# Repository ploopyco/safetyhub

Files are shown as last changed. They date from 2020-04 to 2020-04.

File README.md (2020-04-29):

# The Ploopy Safetyhub

If you're a certain kind of tinkerer, you probably have a whole bunch of computers with busted USB ports. Maybe you dropped a screwdriver on a dev board one time, or accidentally charged your EV prototype through the debugging interface. Either way, you oopsied and now your shiny Thinkpad (or Macbook, we don't judge) has a dead USB port.

A "simple" way to avoid this problem is to use a "powered" USB hub, which protects the upstream port from downstream mischief. The fact that we looked for a reliable one and couldn't find it is the reason this project exists. In short:

## The Ploopy Safetyhub was explicitly designed to protect your computer from the antics of your bus-powered devices. No more murdering the USB ports on your shiny computer!

Specifically:

- The 5V line from the upstream data port is not connected to any downstream 5V lines, so a downstream short can't damage your computer.
- The data lines have good ESD protection on both the upstream and downstream sides, serving as a first (and second) line of defense against ESD strikes.
- Downstream 5V lines have FET-based (fast, recoverable) over-current protection for downstream shorts. All downstream 5V power comes from a separate USB-C port (which would typically have a robust wall-wart plugged into it).

Spec-wise:

- 3 downstream USB 2.0 ports, including one port rated for 1.5A charging.
- Microchip USB2513B hub controller.
- Separate upstream USB-C connectors for data (USB 2.0) and power (up to 3A).
- LED indicators to indicate whether a port is active/faulted.
- No direct connections between upstream and downstream power/data lines.
- Heavy-duty ESD protection (IEC 61000-4-2 class 4).

The way it works is simple: there are no direct power/data connections between your computer and downstream devices. Power comes from a sturdy wall-wart, and beefy ESD protection makes sure nothing zappy makes it to your computer. As long as your device is bus-powered (i.e. doesn't have a power supply of its' own), the Safetyhub should protect your computer.

## Schematics

Electrical design files are in Altium-specific formats, but if you just want to look, there's a PDF version here: https://github.com/ploopyco/safetyhub/blob/master/Electrical/HubSchematics.pdf

## Obligatory Warnings

The Safetyhub is not electrically isolated, and won't protect from high voltages, ground loops and other dangerous situations. If your downstream device has its' own power supply/has high voltages present/presents other electrical hazards, you'll need a real isolation barrier. If you're not sure if this paragraph describes your situation, please consult with someone who can help you avoid electrocution/accidents that give you superpowers.

## Under what license is this released?

The hub is released under OHL CERN v1.2. Check the respective directories for full license text.

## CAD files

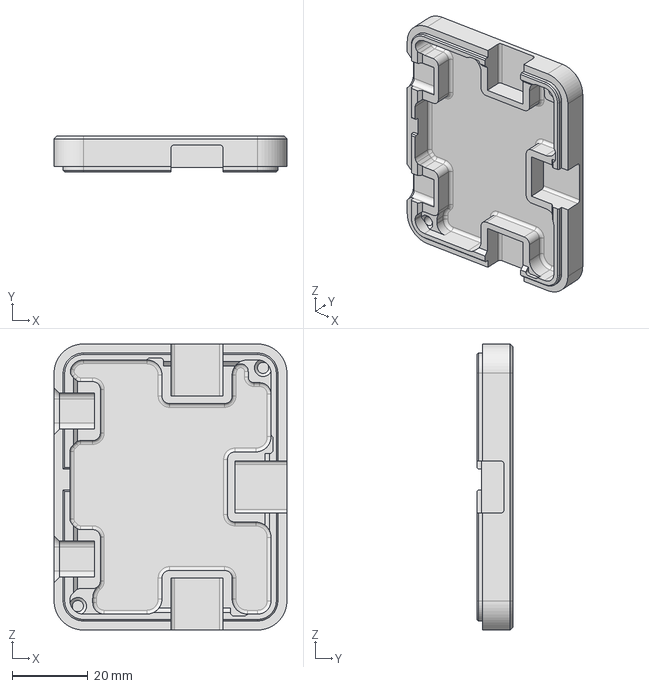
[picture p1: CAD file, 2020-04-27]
Mechanical/STEPs/HUB-001.stp
61.4 x 9.58 x 75.4 mm

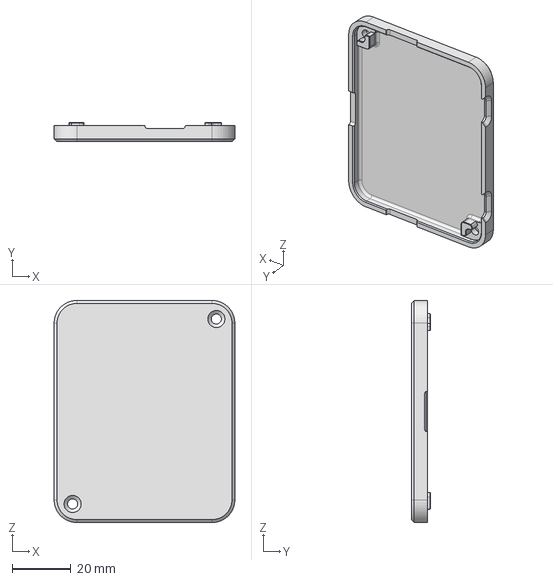
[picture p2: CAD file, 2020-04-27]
Mechanical/STEPs/HUB-002.stp
61.4 x 6.60 x 75.4 mm

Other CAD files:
Mechanical/STLs/HUB-001.stl
Mechanical/STLs/HUB-002.stl

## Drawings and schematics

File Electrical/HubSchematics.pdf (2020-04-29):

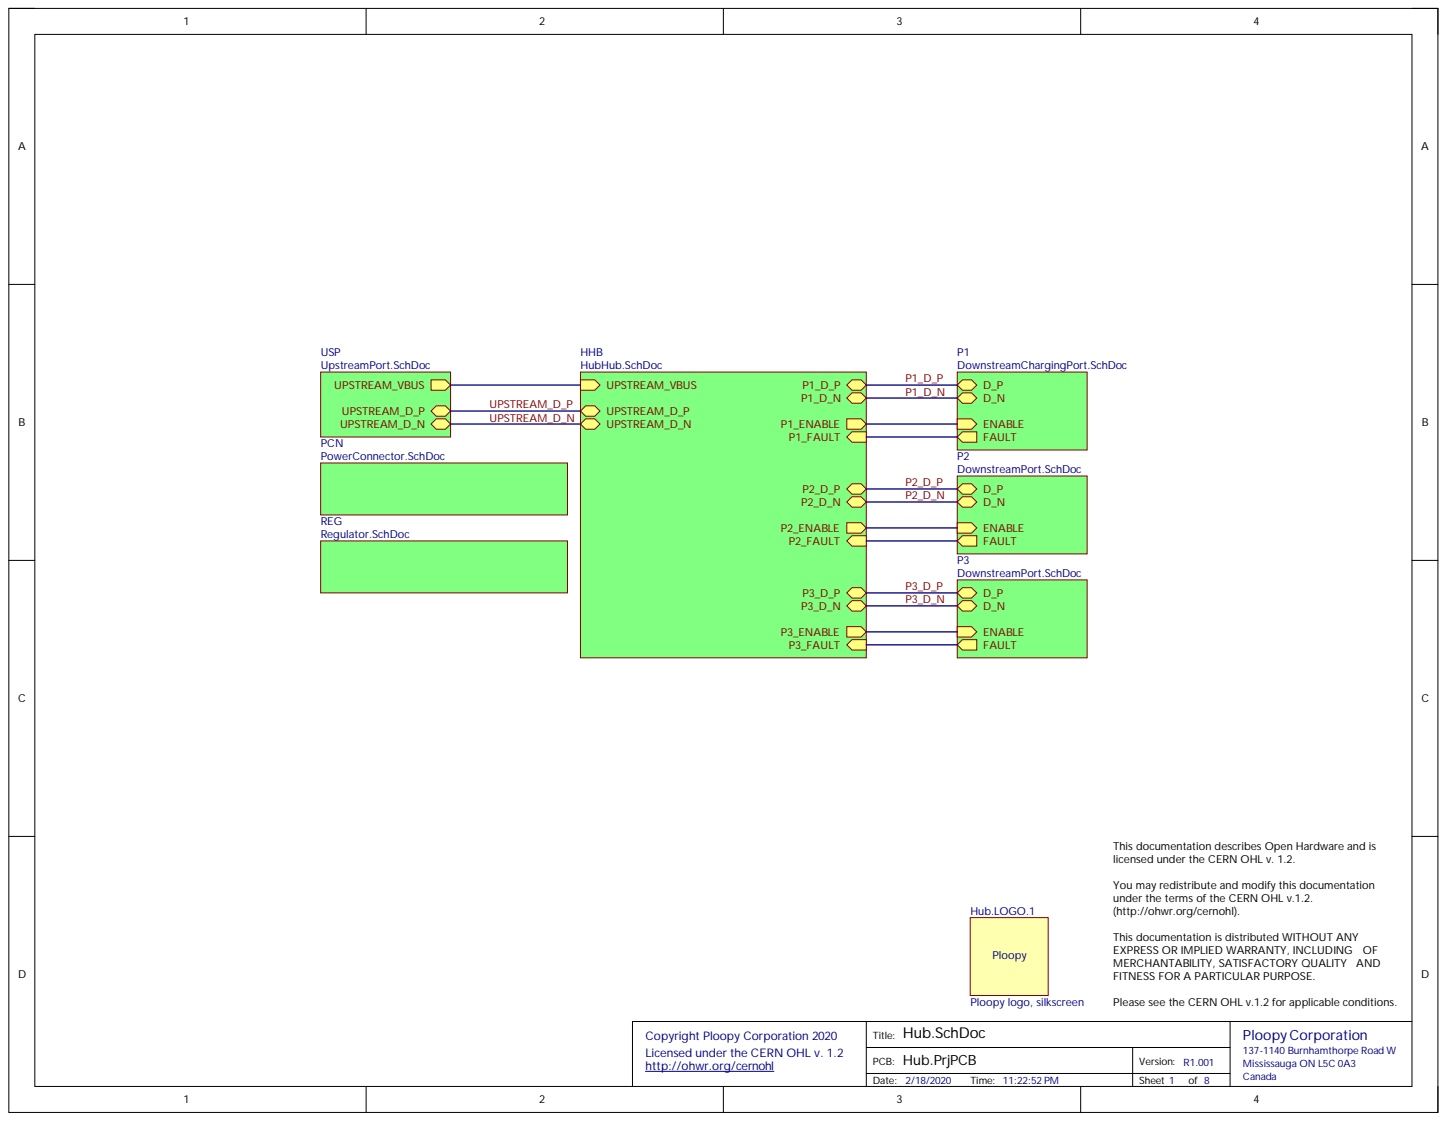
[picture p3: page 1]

This documentation describes Open Hardware and is
licensed under the CERN OHL v. 1.2.

You may redistribute and modify this documentation
under the terms of the CERN OHL v.1.2.
(http://ohwr.org/cernohl).

This documentation is distributed WITHOUT ANY
EXPRESS OR IMPLIED WARRANTY, INCLUDING OF
MERCHANTABILITY, SATISFACTORY QUALITY AND
FITNESS FOR A PARTICULAR PURPOSE.

Please see the CERN OHL v.1.2 for applicable conditions.

Copyright Ploopy Corporation 2020
Licensed under the CERN OHL v. 1.2
http://ohwr.org/cernohl

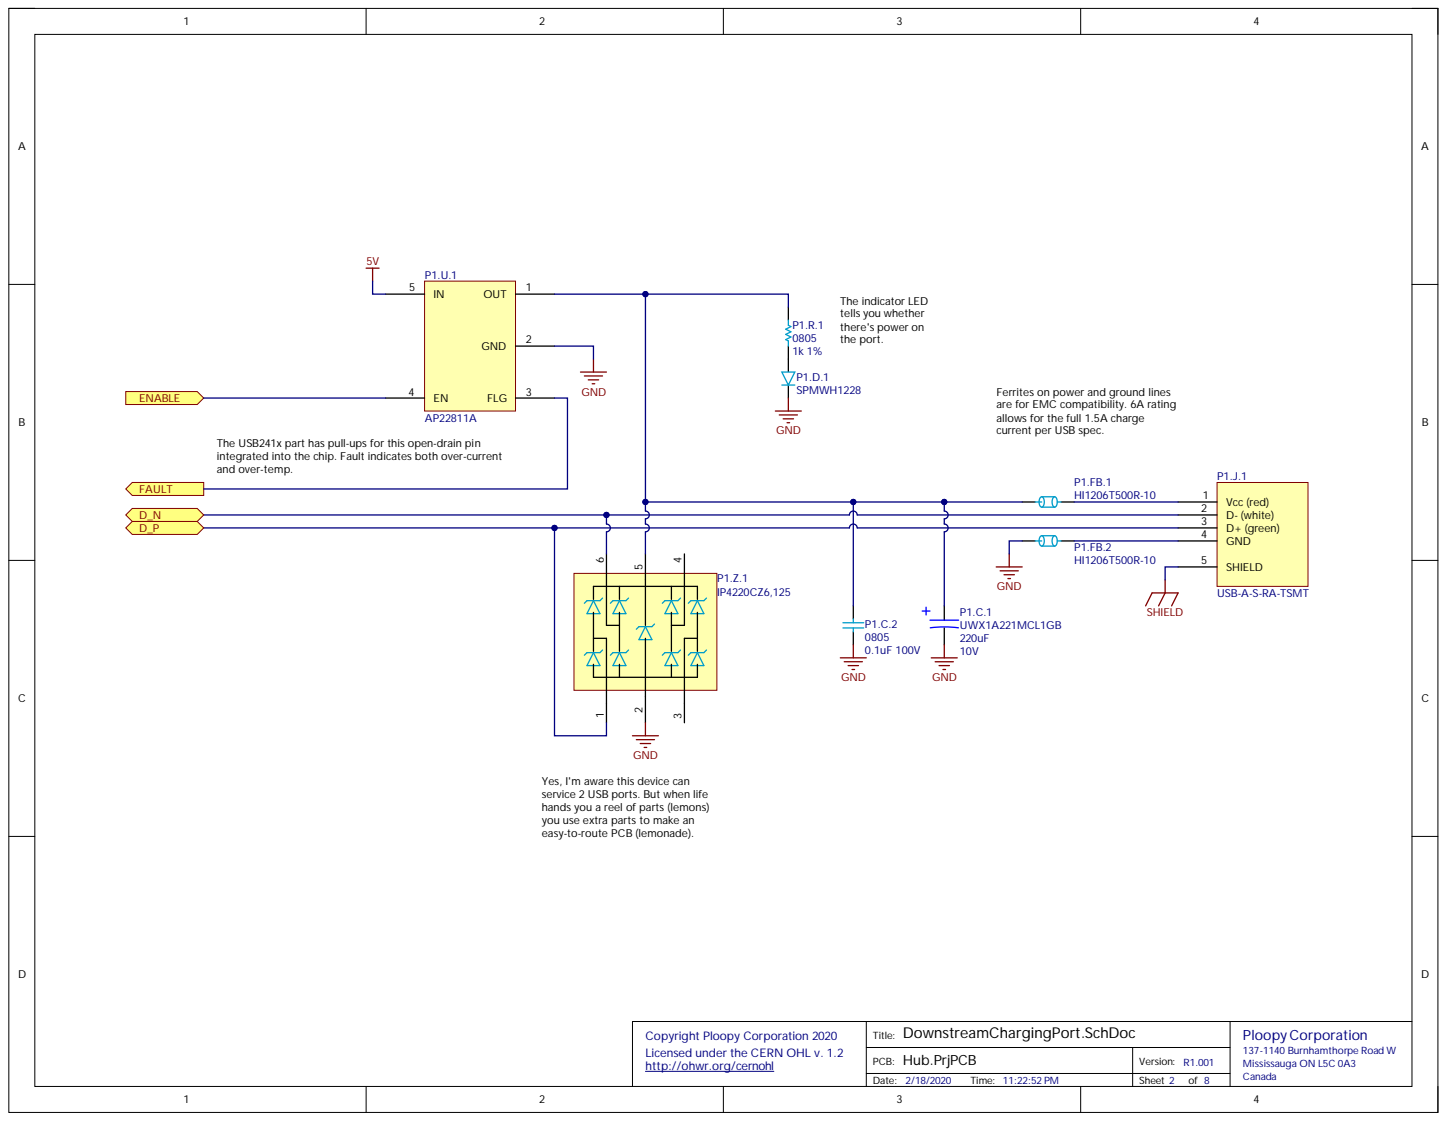
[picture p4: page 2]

Ferrites on power and ground lines
are for EM
allows for the full 1.5A charge
current per USB s

The USB
integrated into the chip. Fault indicates both over-current
and over-tem

41x part has pull-up

Yes, I'm aware this device can service 2 USB ports. But when life

s you a reel of parts (lemons)
hand
you use extra parts to make an
easy-to-route PC

Cop
Licensed under the CE
http

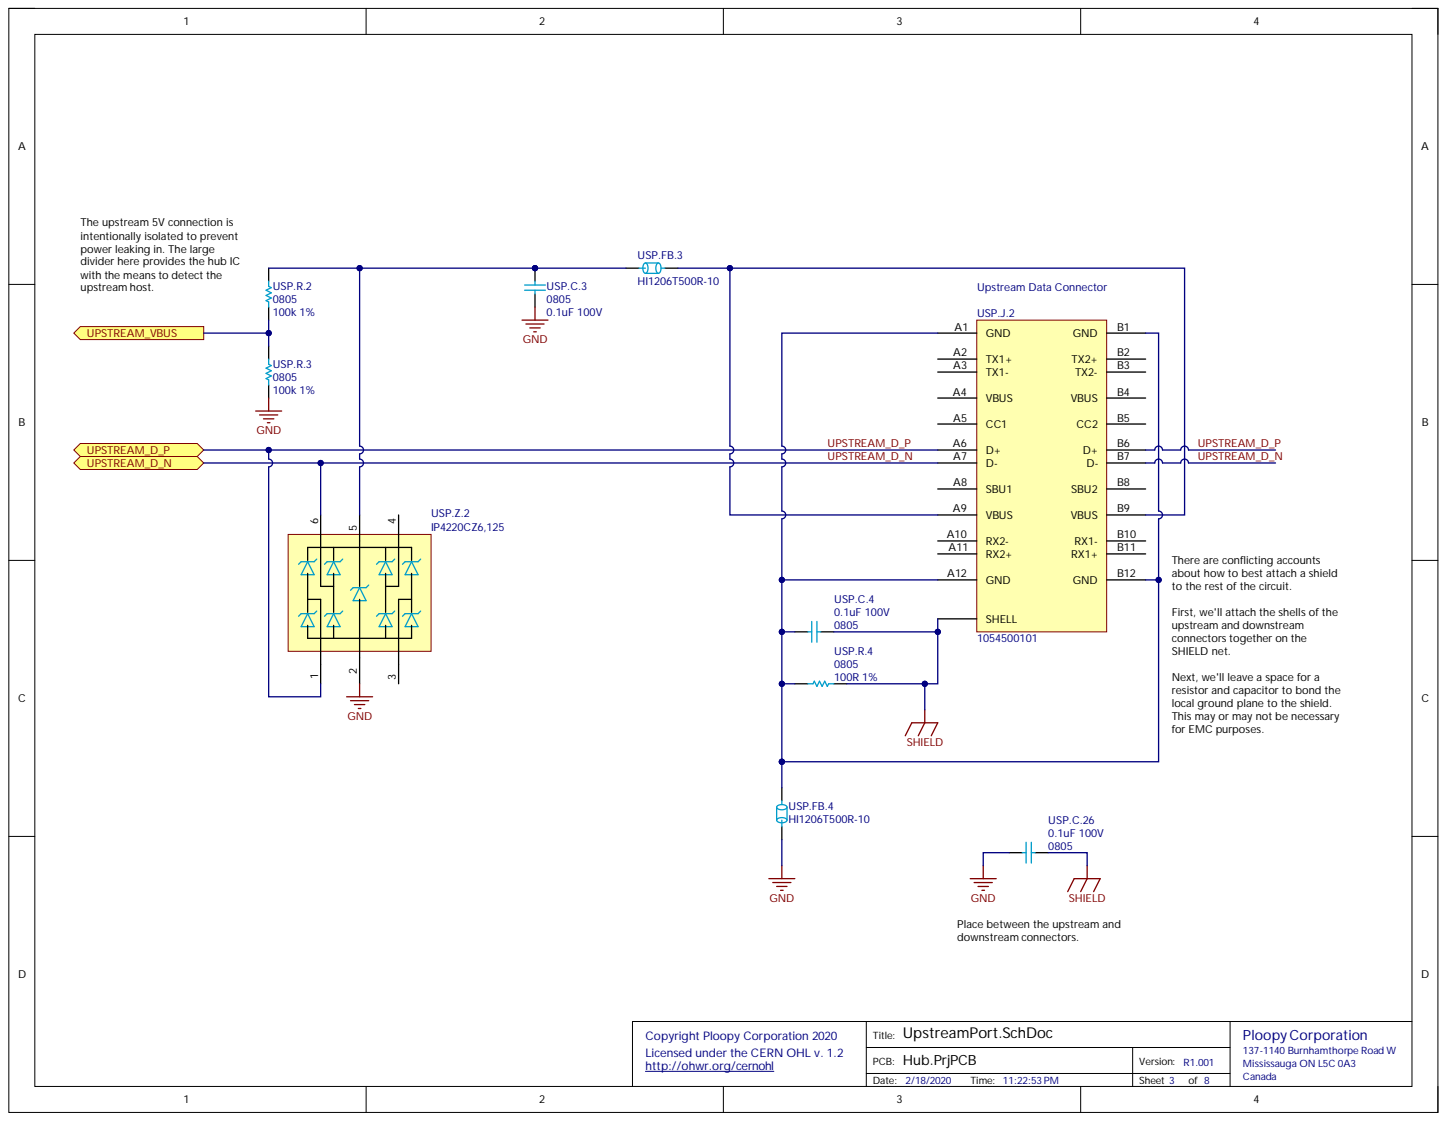
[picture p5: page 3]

The upstream 5V connection is
intentionally isolated to prevent
power leaking in. The large
divider here provides the hub IC
with the means to detect the
upstream host.

There are conflicting accounts
about how to best attach a shield
to the rest of the circuit.

First, we'll attach the shells of the
upstream and downstream
connectors together on the
SHIELD net.

Next, we'll leave a space for a
resistor and capacitor to bond the
local ground plane to the shield.
This may or may not be necessary
for EMC purposes.

Place between the upstream and
downstream connectors.

Copyright Ploopy Corporation 2020
Licensed under the CERN OHL v. 1.2
http://ohwr.org/cernohl

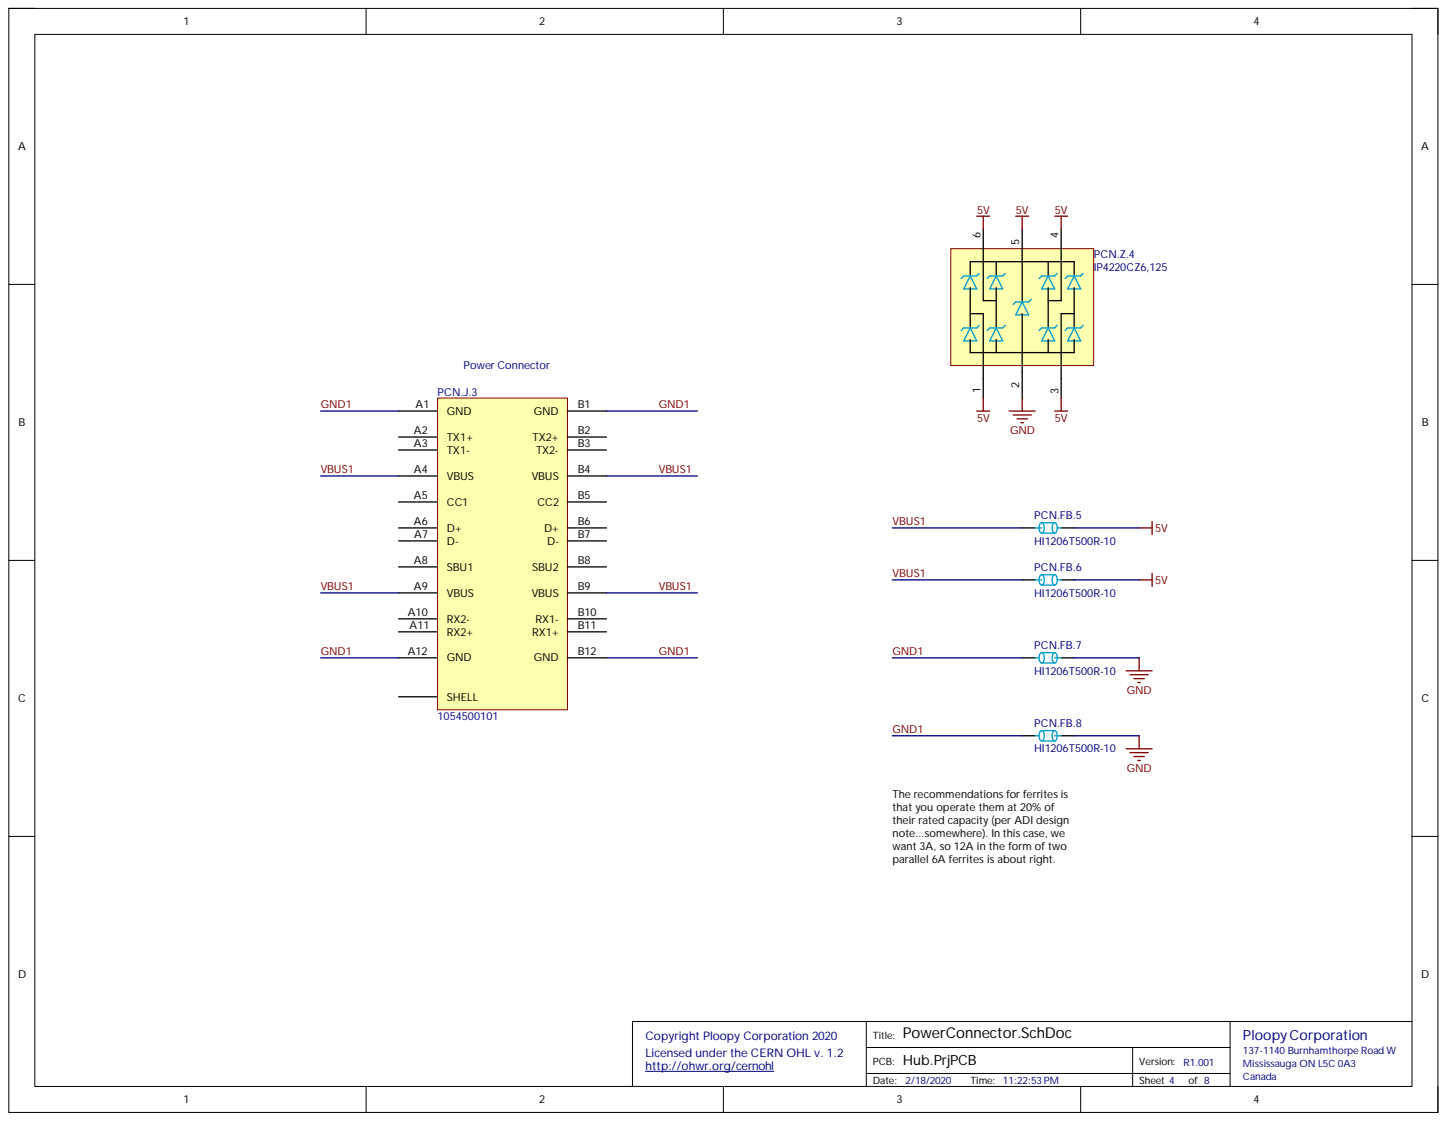
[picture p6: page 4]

The recom
that you operate them at 20% of
their rated capacity (per A
note...somewhere).
want 3A, so 12A in the form of two parallel 6A ferrites is about right.

mendations for ferrites is

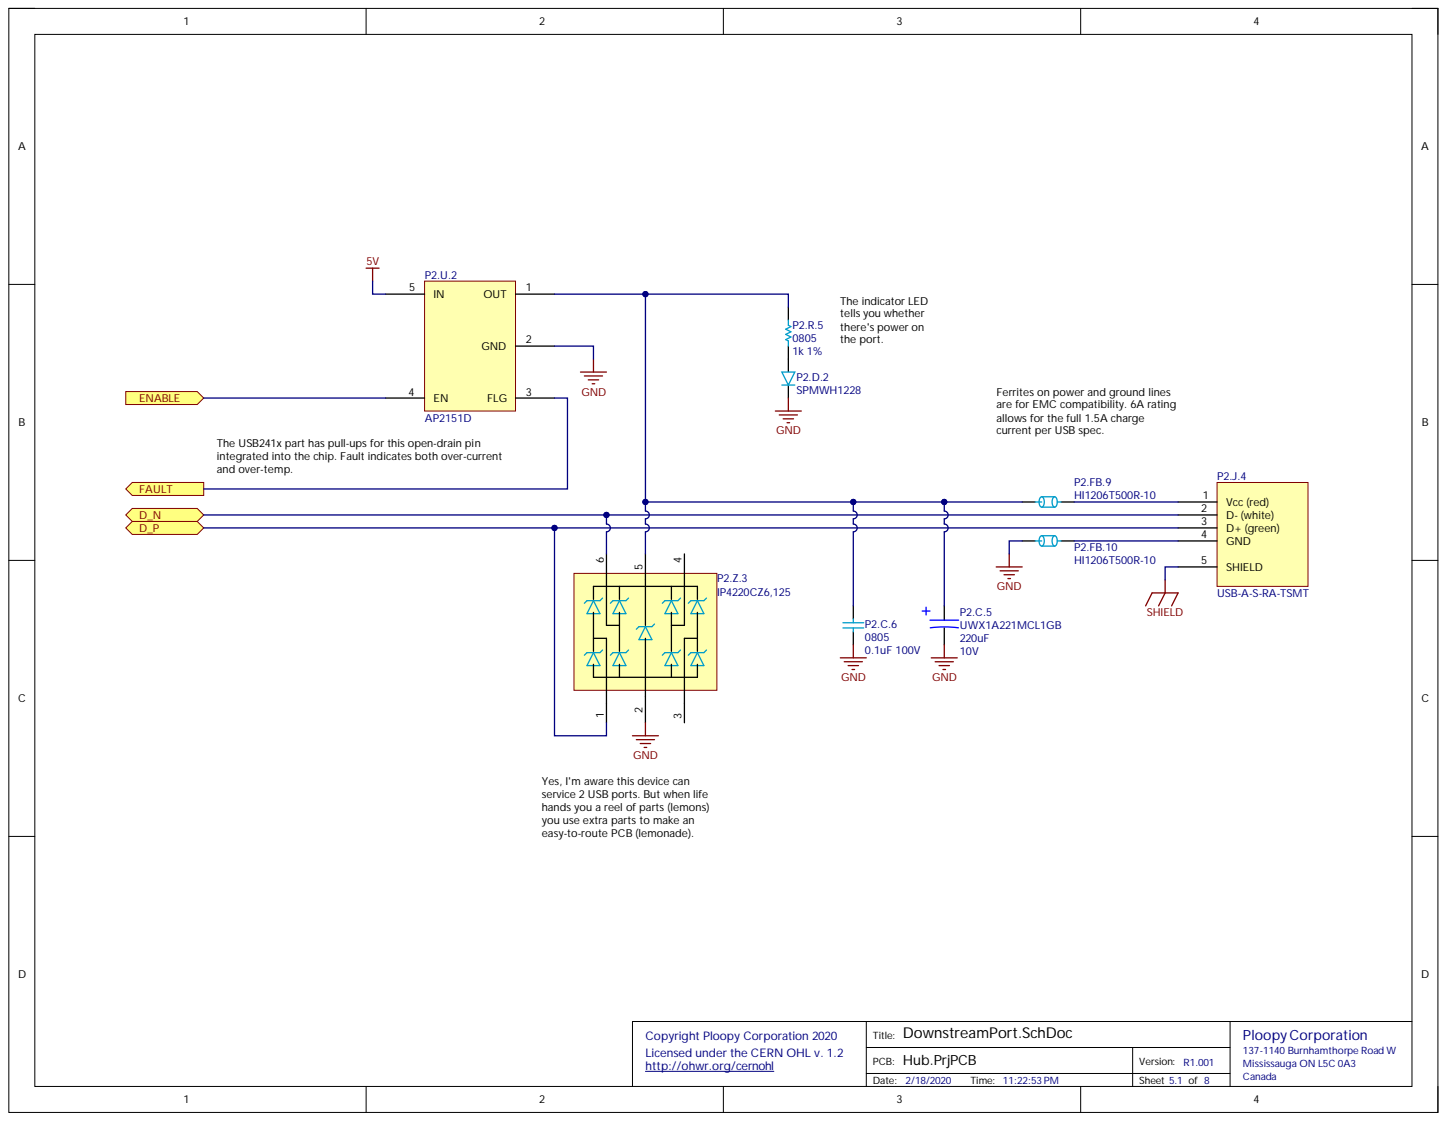
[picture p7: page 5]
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

The USB
integrated into the chip. Fault indicates both over-current
and over-tem

41x part has pull-up

Yes, I'm aware this device can service 2 USB ports. But when life

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

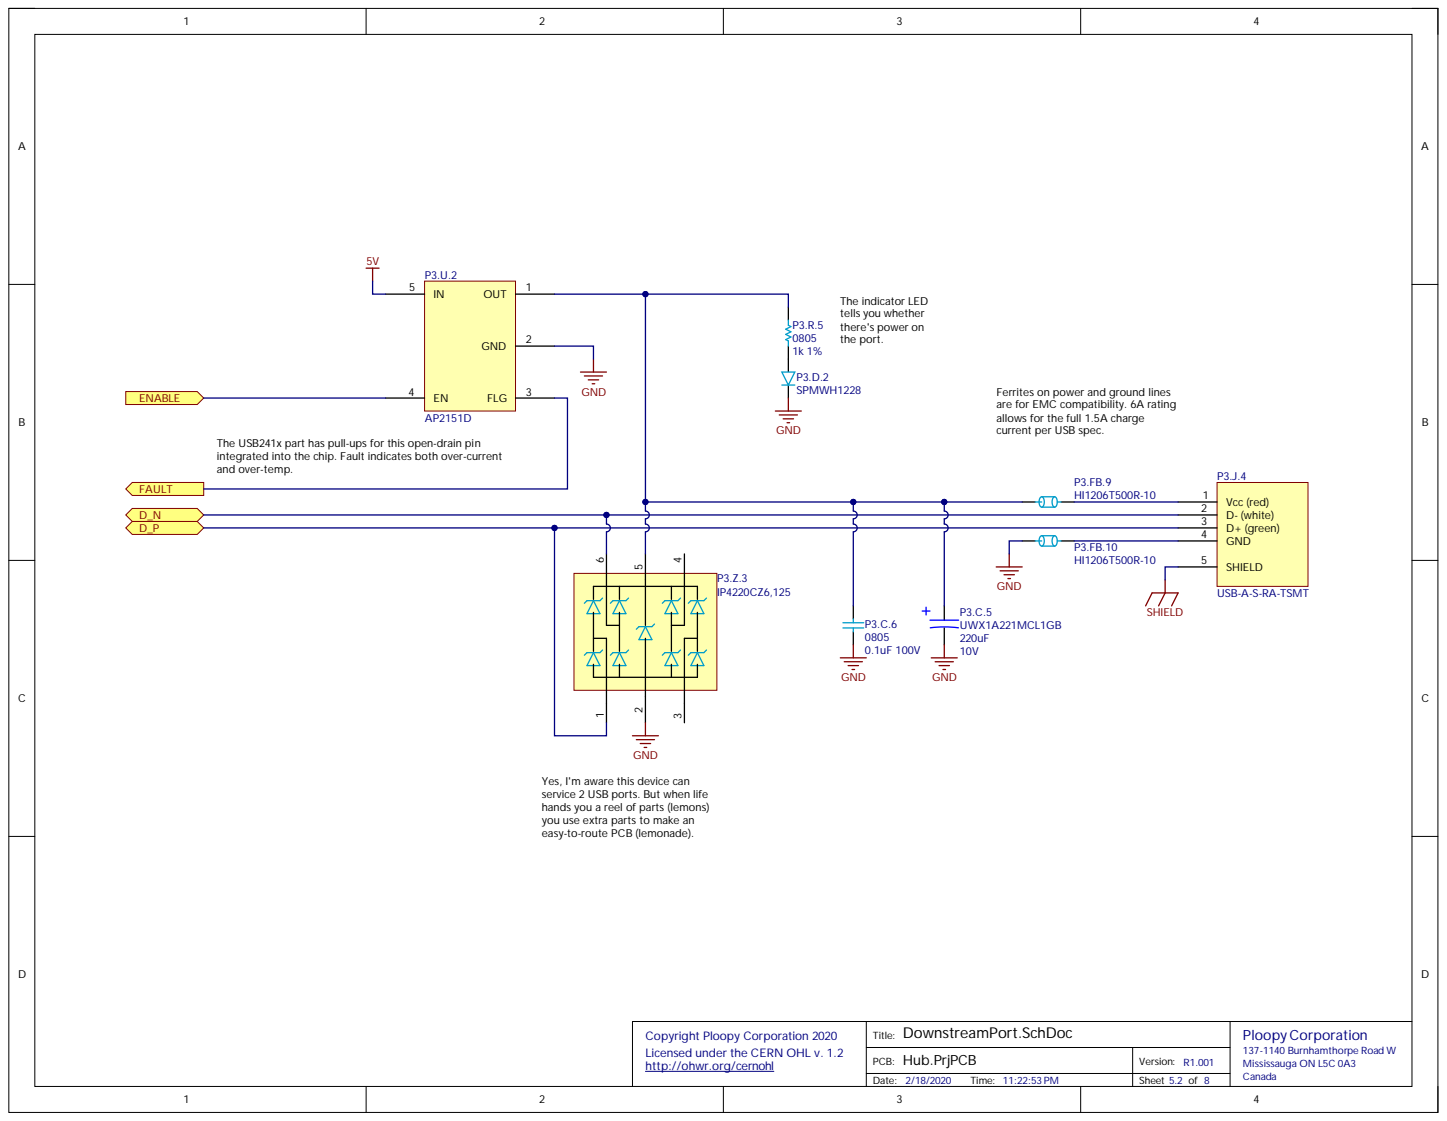
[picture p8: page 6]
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

The USB
integrated into the chip. Fault indicates both over-current
and over-tem

41x part has pull-up

Yes, I'm aware this device can service 2 USB ports. But when life

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

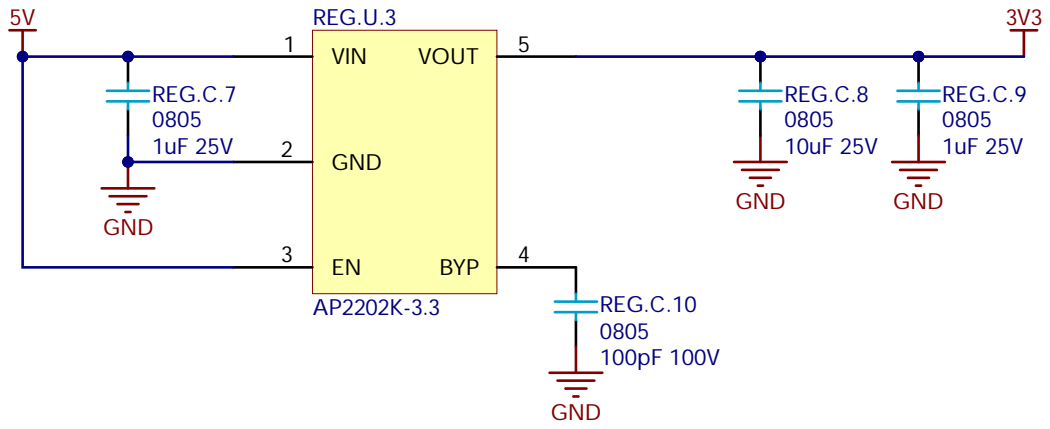
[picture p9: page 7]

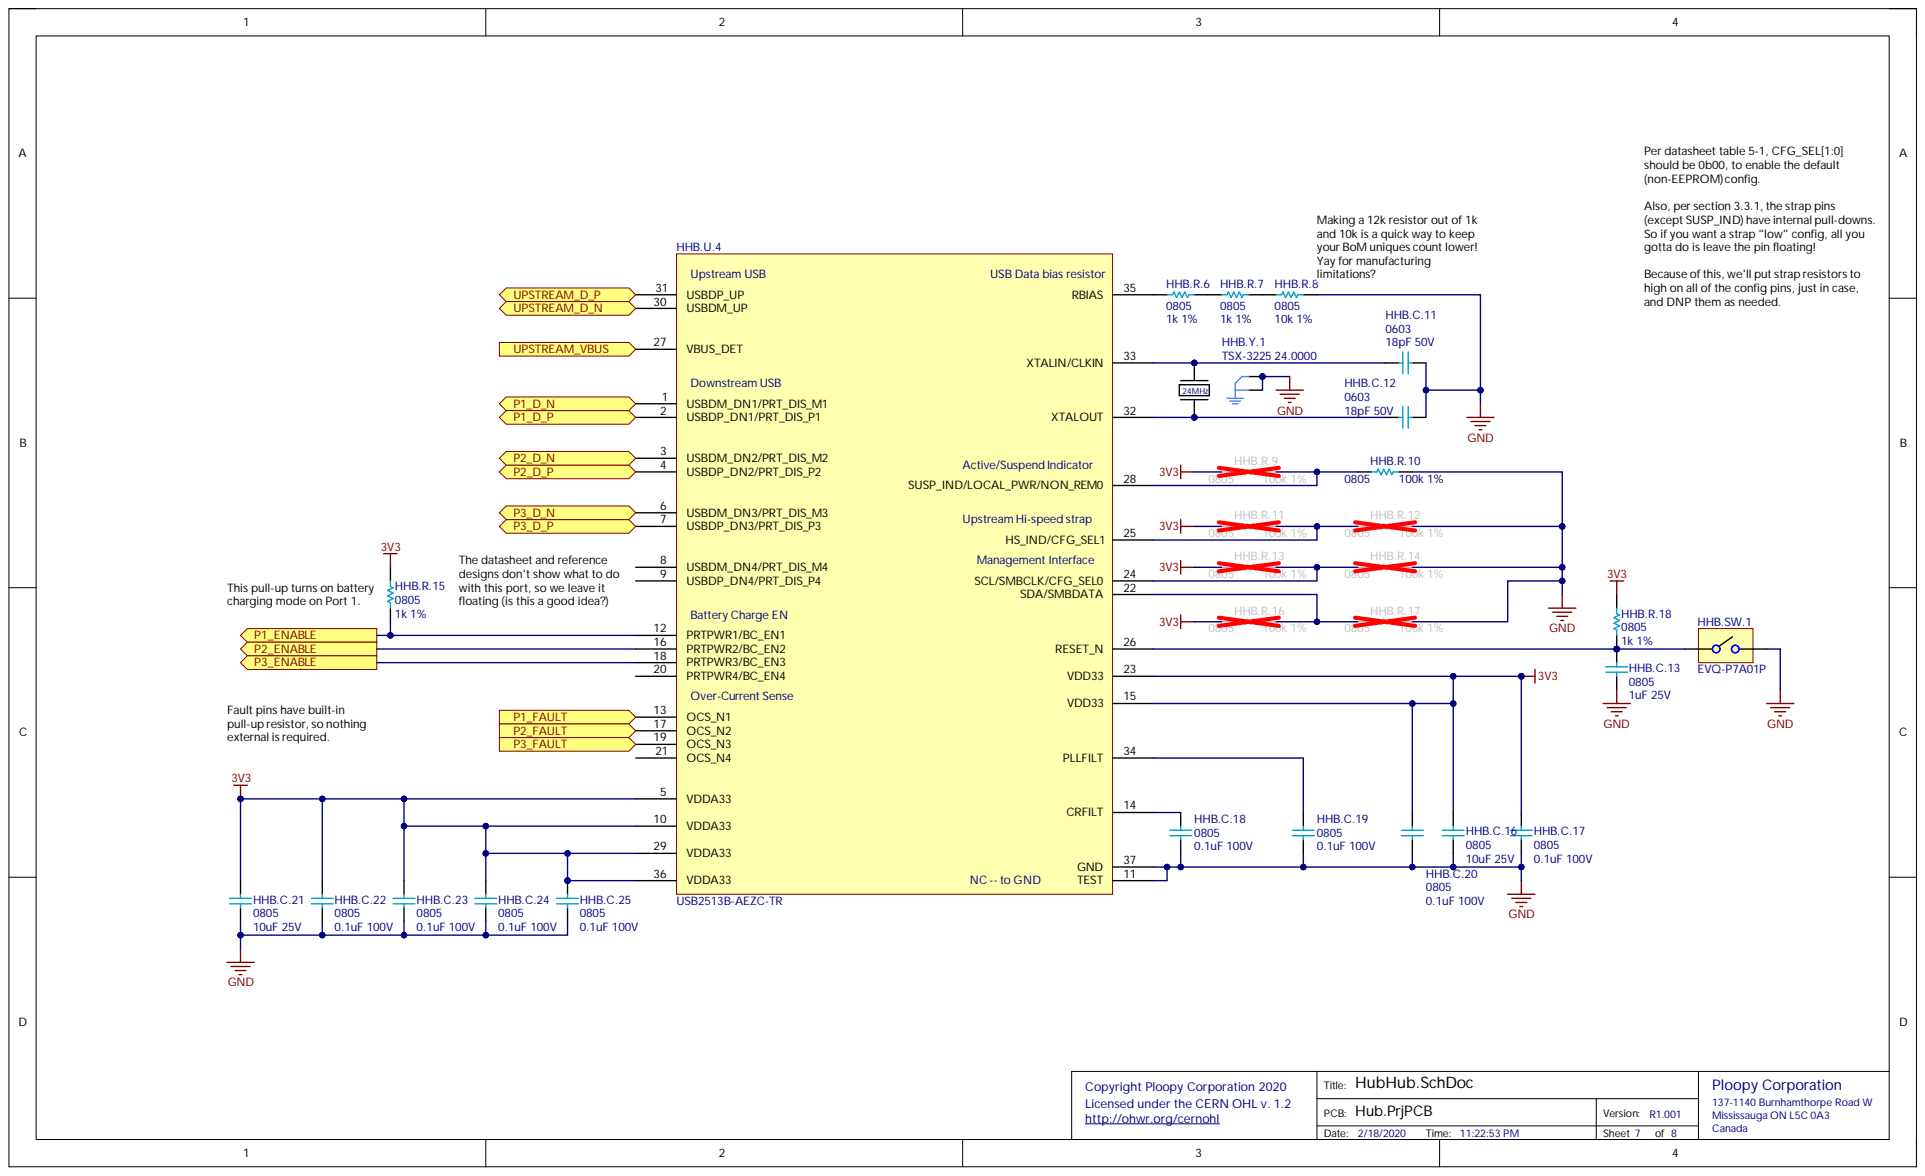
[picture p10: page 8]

USBDM_U
Downstream USB Battery Charge EN Over-Current Sense
USBDM_DN1/PR

ing mode on Port 1.

C opy righ t Plo opy C o rpo ratio n 2 0 2 0 Lice n sed u nde r t h e CERN O HL v. 1.2 h t tp://o hwr.o rg/ce r n o h l | T i t le: HubHub .SchD o c | Ploop y Corporation 137-1140 Burnha m tho rpe Ro ad W M i ss i ssauga ON L5C 0A 3 C anada

Hub.PrjPC B P C B : | Vers i o n : R1.001

D a te: 2/18/2020 T i me: 11:22:53 P M | Sheet 7 o f 8

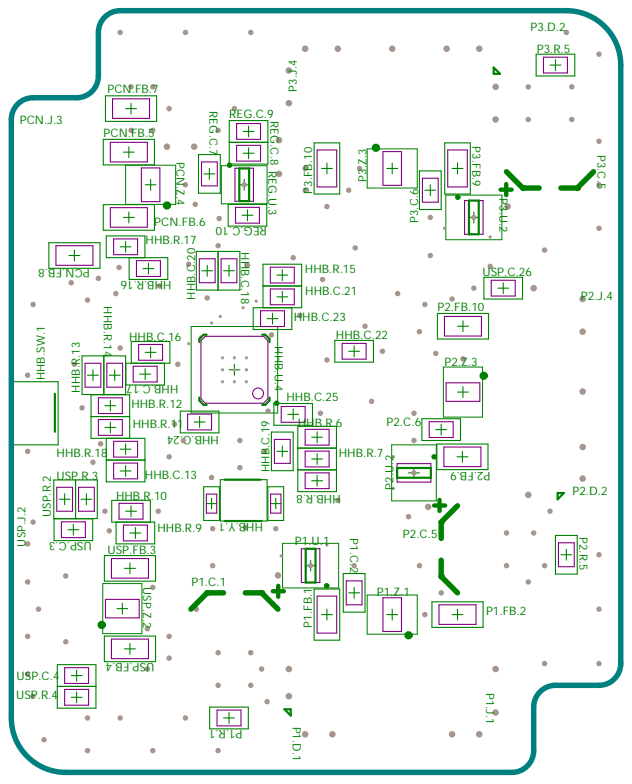
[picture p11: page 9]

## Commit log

2020-04-27 R1.001 PCB design files.
    [Capacitors.PcbLib, Capacitors.SchLib, Chip_Passives.PcbLib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]
2020-04-27 R1.001 STLs and STEP files for the plastic enclosure.
    [HUB-001.stl, HUB-001.stp, HUB-002.stl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]
2020-04-29 PDF version of the R1.001 schematics.
